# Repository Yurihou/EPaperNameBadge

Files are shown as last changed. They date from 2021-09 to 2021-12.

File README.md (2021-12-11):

# EPaperNameBadge
This is a name badge using E-Paper screen which shows various information including name, status, time, weather and so on. 

522e120fe108bd40b3b348502633d6c

This project uses ESP32 as controller, which is able to connect Bluetooth and Wi-Fi. Related function is developing.

## Hardware
EPaperNameBadge uses YWRobot 2.9 inch E-ink screen as main screen, which displays 296x128 monochrome(maybe with red pixel?) bitmap on itself.



The screen use GDEW029T5 as driver. The datasheet can be found in path /datasheet.

The screen uses SPI interface connected to an ESP32. There is 8 wires to connect:

|EPaper|ESP32|
|---|---|
|BUSY|17|
|RST|22|
|DC|21|
|CS|5|
|MOSI(DIN)|23|
|SCLK|18|
|VCC|3V3 or 5V|
|GND|GND|

We also added 3 LED to show Power, Bluetooth and Wi-Fi (preserved) connection status:
|LED|Anode|Cathode|
|---|-----|---|
|Power|5V/3V3|GND|
|Bluetooth|12|GND|
|Wi-Fi|14|GND|

For offline time display, we added a DS1302 to store time data:
|DS1302|ESP32|
|---|-----|
|DAT(I/O)|25|
|CLK|32|
|RST(EN)|33|

## Software
In fact, we can create a library about EPaper screen. However, in order to test the screen, we use just basic SPI library to control the screen.

The programe refers to the example code from YWRobot.

### Bluetooth AT command
To control the EPaper, time chip, Wi-Fi and so on, we use AT command.

To send command, we use Bluetooth serial APP (such as "Bluetooth Serial" on Android or Harmony OS, "BluTerm" on iOS, any serial tool on Windows, Linux or MacOS), power on the EPaper, connect the Bluetooth "EPapaer_Screen", then open Bluetooth serial APP and connect the bluetooth serial. Then we just send AT command thru Bluetooth.

394275306ac3181d10a8feeccb368d2


Detailed AT command list will be upload later. Here comes basic examples:

|AT Command|Function|
|---|---|
|AT+TIME?|Check local time.|
|AT+TIME 2021/10/02,10:00,7|Set local time to 10:00, Oct.2, 2021, Sunday.|
|AT+CJWAP?|Check current Wi-Fi status.|
|AT+CJWAP Tsinghua-2G|Connect to Wi-Fi "Tsinghua-2G" without password.|
|AT+CJWAP Tsinghua-2G 1145141919810|Connect to Wi-Fi "Tsinghua-2G" with password "1145141919810".|
|AT+CWLAP|Scan and display all available Wi-Fi.|
|AT+CWQAP|Disconnect Wi-Fi.|

- Note: WPA2 Camps Networks are not available for this program and I cannot find any solution now emmm...

## Update Log
2021.9.26 V0.1.0 

- First Version Uploaded.

2021.10.1 V0.1.1

- Bluetooth Serial added.
- Three status LED added.
- Rewrite EPapae control as a class.
- Back shell (temporary version with handmade circuit board) uploaded.
- EInk Screen datasheet uploaded.

2021.10.02 V0.2.0

- DS1302 Added.
- Simple AT command added.
- Able to connect to Wi-Fi.

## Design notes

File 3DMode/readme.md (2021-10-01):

Note: The 3D moel is created by Solidworks 2021.

If lower version file is needed, please contact yurihou@qq.com 

"前壳" means "front shell", "后壳" means back shell in Chinese.

To build up front and back shell together, 4 M3x25 screw bolts and 4 M3x5 inlaid nuts are needed. Please use soldering iron to stick nuts into front shell, then fix back shell with bolts.

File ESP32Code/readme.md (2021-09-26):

This code is written using Arduino ESP32 library.

File picdata.h stores picture data.

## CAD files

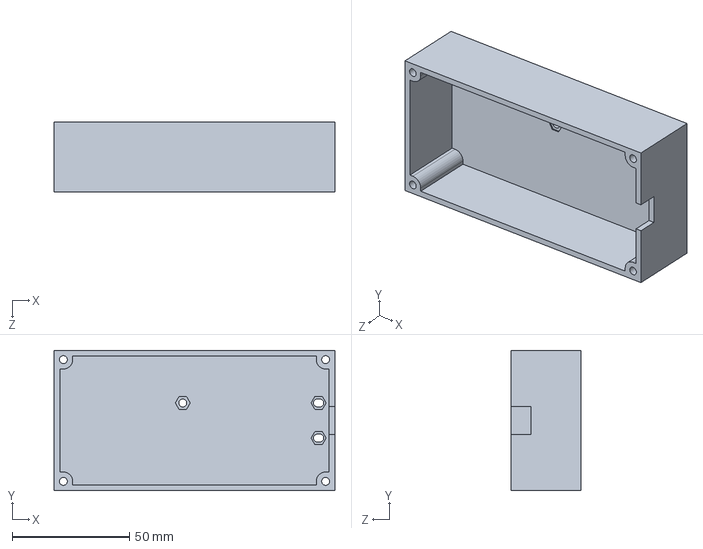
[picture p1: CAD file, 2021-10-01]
3DMode/后壳new.SLDPRT
120.0 x 60.0 x 30.0 mm

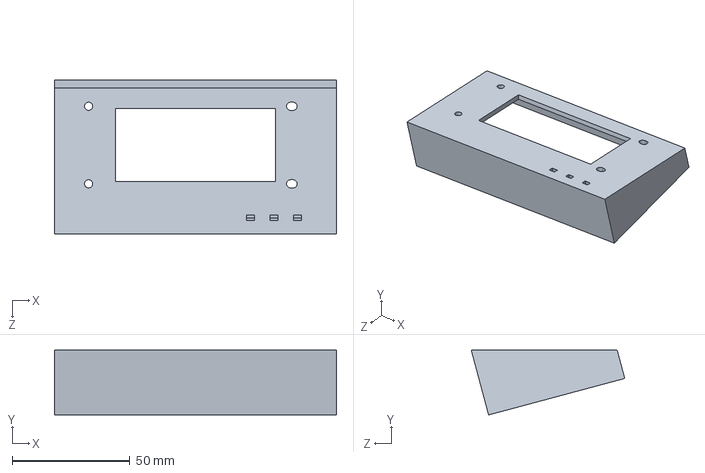
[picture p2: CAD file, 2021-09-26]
3DMode/前壳new.SLDPRT
120.0 x 27.6 x 65.4 mm

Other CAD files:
3DMode/前壳1.STL
3DMode/后壳new.STL

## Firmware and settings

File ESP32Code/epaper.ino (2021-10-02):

#include <ETH.h>
#include <WiFi.h>
#include <WiFiAP.h>
#include <WiFiClient.h>
#include <WiFiGeneric.h>
#include <WiFiMulti.h>
#include <WiFiScan.h>
#include <WiFiServer.h>
#include <WiFiSTA.h>
#include <WiFiType.h>
#include <WiFiUdp.h>

#include <SPI.h>
#include <BluetoothSerial.h>
#include <Ds1302.h>

#include "globalvar.h"
#include "screen.h"
#include "atcommand.h"
#include "wifiapp.h"

#if !defined(CONFIG_BT_ENABLED) || !defined(CONFIG_BLUEDROID_ENABLED)
#error Bluetooth is not enabled! Please run `make menuconfig` to and enable it
#endif

#define PIN_ENA 33
#define PIN_CLK 32
#define PIN_DAT 25

eInkScreen screen;
BluetoothSerial SerialBT;
Ds1302 rtc(PIN_ENA, PIN_CLK, PIN_DAT);

Ds1302::DateTime dt = {
  .year = 21,
  .month = 10,
  .day = 1,
  .hour = 20,
  .minute = 0,
  .second = 0,
  .dow = Ds1302::DOW_FRI
};

char wifiSSID[20] = "";
char wifiPswd[20] = "";

#define BluetoothLED 12
#define WiFiLED 14

// extern char screenData[];

void setup() {
  // put your setup code here, to run once:
  int i;
  Serial.begin(115200);
  rtc.init();
  if (rtc.isHalted())
  {
    Serial.println("RTC is halted. Setting time...");
    rtc.setDateTime(&dt);
  }
  pinMode(BluetoothLED, OUTPUT);
  pinMode(WiFiLED, OUTPUT);
  SerialBT.begin("EPapaer_Screen"); //Bluetooth device name
  delay(1);
  screen.screenGlobalChange();
}

void loop() {
  // put your main code here, to run repeatedly:
  int buff = 0;
  if (SerialBT.available())//Deal with AT command
  {
    buff = getATCommand();
    switch (buff)
    {
      case notCorrectCommand:
        SerialBT.printf("This is not a correct command.\n"); break;
      case notCorrectAT:
        SerialBT.printf("This is not a correct AT command.\n"); break;
      case readTime:
        Ds1302::DateTime now;
        rtc.getDateTime(&now);
        SerialBT.printf("Current Time: 20%02d/%02d/%02d %02d:%02d:%02d\n", now.year, now.month, now.day, now.hour, now.minute, now.second);
        break;
      case setTime:
        rtc.setDateTime(&dt);
        rtc.getDateTime(&now);
        SerialBT.printf("Current Time: 20%02d/%02d/%02d %02d:%02d:%02d\n", now.year, now.month, now.day, now.hour, now.minute, now.second);
        break;
      case scanWifiAP:
        wifiScan();
        break;
      case checkWiFi:
        checkWiFi1();
        break;
      case connWiFi:
        connWiFi1();
        break;
      case connWiFiWithPswd:
        connWiFi2();
        break;
      case disconnectWiFi:
        disconnWiFi0();
        break;
    }
  }

  //Detect whether Bluetooth is connected and turn on or off GPIO12
  digitalWrite(BluetoothLED, SerialBT.connected());
  digitalWrite(WiFiLED, WiFi.isConnected());

  delay(50);
}

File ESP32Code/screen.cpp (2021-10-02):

#include "screen.h"
#include <Arduino.h>
#include <SPI.h>

#include "globalvar.h"
#include "picdata.h"

// char screenData[4736] = {0};

//SPIClass screen(VSPI);

int floor_division(int i, int j)
{
  int k;
  double i1 = (double)i, j1 = (double)j, k1;
  k1 = i1 / j1;
  k = i / j;
  if (k1 - double(k) == 0)return k;
  else return k + 1;
}

eInkScreen::eInkScreen(): screen(VSPI), partialRefreshTime(0)
{
  //SCLK = 18, MISO = 19, MOSI = 23, CS = 5
  pinMode(DC, OUTPUT);
  pinMode(RST, OUTPUT);
  pinMode(SS, OUTPUT);
  pinMode(ISBUSY, INPUT);
  screen.begin();
}

void eInkScreen::sendByte(char dc, char data)
{
  //while (digitalRead(ISBUSY));
  digitalWrite(DC, dc);
  screen.beginTransaction(SPISettings(spiClk, MSBFIRST, SPI_MODE0));
  digitalWrite(VSPI_SS, LOW); //pull SS slow to prep other end for transfer
  screen.transfer(data);
  digitalWrite(VSPI_SS, HIGH); //pull ss high to signify end of data transfer
  screen.endTransaction();
}

void eInkScreen::isScreenBusy()
{
  char busy = 0;
  do
  {
    sendByte(CMD, 0x71);
    busy = digitalRead(ISBUSY);
    busy = !(busy & 0x01);
  }
  while (busy);
}

void eInkScreen::screenInit()
{
  //Resolution
  char HRES = 0x80;          //128
  char VRES_byte1 = 0x01;      //296
  char VRES_byte2 = 0x28;

  digitalWrite(RST, LOW);   // Module reset
  delay(100); //At least 10ms
  digitalWrite(RST, HIGH);
  delay(100);

  sendByte(CMD, 0x06);        //boost soft start
  sendByte(DAT, 0x17);  //A
  sendByte(DAT, 0x17);  //B
  sendByte(DAT, 0x17);  //C

  sendByte(CMD, 0x04); //Power on
  //waiting for the electronic paper IC to release the idle signal
  isScreenBusy();
  delay(200);

  sendByte(CMD, 0x00);    //panel setting
  sendByte(DAT, 0x1f);   //LUT from OTP
  sendByte(DAT, 0x0d);   //VCOM to 0V

  sendByte(CMD, 0x61);    //resolution setting
  sendByte(DAT, HRES);
  sendByte(DAT, VRES_byte1);
  sendByte(DAT, VRES_byte2);

  sendByte(CMD, 0X50);    //VCOM AND DATA INTERVAL SETTING
  sendByte(DAT, 0x97);   //WBmode:VBDF 17|D7 VBDW 97 VBDB 57   WBRmode:VBDF F7 VBDW 77 VBDB 37  VBDR B7
}

void eInkScreen::screenWrite()
{
  //Display Test
  unsigned int i, j;
  sendByte(CMD, 0x10);        //Transfer old data
  for (i = 0; i < 4736; i++)
    sendByte(DAT, 0xFF);

  sendByte(CMD, 0x13);        //Transfer new data
  for (i = 0; i < 296; i++)
  {
    for (j = 0; j < 16; j++)
      sendByte(DAT, ~screenData[(296 - i) * 16 + j]);
      //For screen, 0 stands for black and 1 for white, so command reversed color here.
  }
}

void eInkScreen::screenRefresh()
{
  sendByte(CMD, 0x12);     //DISPLAY REFRESH
  delay(100);          //!!!The delay here is necessary, 200uS at least!!!
  isScreenBusy();
}

void eInkScreen::screenSleep()
{
  sendByte(CMD, 0X50);  //VCOM AND DATA INTERVAL SETTING
  sendByte(DAT, 0xf7);

  sendByte(CMD, 0X02);   //power off
  isScreenBusy();
  sendByte(CMD, 0X07);   //deep sleep
  sendByte(DAT, 0xA5);
}

void eInkScreen::screenGlobalChange()
{
  screenInit();
  screenWrite();
  screenRefresh();
  screenSleep();
  partialRefreshTime = 0;
}

//Because of the position of the screen, x=0 on top and y=0 on left
//Thus, x means vertical axis and y means horizontal.
//What's more, because image stores in whole 8-bit bytes for 1/16 column,
//Partial refresh needs a height of 8 pixel or its multiples.
void eInkScreen::screenPartialChange(int y1, int x1, int y2, int x2)
{
  screenInit();
  if (partialRefreshTime < 5)
  {
    unsigned int datas, i, j;

    sendByte(CMD, 0x91);   //This command makes the display enter partial mode
    sendByte(CMD, 0x90);   //resolution setting
    sendByte(DAT, x1);   //x-start
    sendByte(DAT, x2 - 1); //x-end

    sendByte(DAT, y1 / 256);
    sendByte(DAT, y1 % 256); //y-start

    sendByte(DAT, y2 / 256);
    sendByte(DAT, y2 % 256 - 1); //y-end
    sendByte(DAT, 0x28);

    datas = (x2 - x1) * (y2 - y1) / 8;
    sendByte(CMD, 0x10);        //writes Old data to SRAM for programming
    for (i = 0; i < datas; i++)
      sendByte(DAT, 0x00);

    sendByte(CMD, 0x13);        //writes New data to SRAM.
    for (i = y1; i < y2; i++)
    {
      for (j = x1 / 8; j < x1 / 8 + floor_division((x2 - x1), 8); j++)
      {
        sendByte(DAT, ~screenData[(296 - i) * 16 + j]);//Command reversed color.
      }
    }
    partialRefreshTime++;
  }
  else
  {
    // To set image clear, after about 5 times of partial refresh, global refresh is needed.
    partialRefreshTime = 0;
    screenWrite();
  }
  screenRefresh();
  screenSleep();
}
